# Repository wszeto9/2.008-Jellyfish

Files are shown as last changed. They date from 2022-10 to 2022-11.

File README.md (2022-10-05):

# 2.008 Jellyfish
 PCA for Jellyfish themed yo-yos for my 2.008 project

# Ordering Instructions
- [Download the manufacturing data](https://github.com/wszeto9/2.008-Jellyfish/raw/main/jellyfish_lights/production.zip)
- Head to https://cart.jlcpcb.com/quote
- Click "Add Gerber File", upload the "Gerber.zip" file from the downloaded files
- Change PCB quantity to 25
- Change PCB Color to White
- Scroll down, select PCB Assembly
- By default they should be selected: Assemble top side, Economic, tooling holes added by JLCPCB, No confirm on parts placement
- Calculated price should show $30.10. Stop if this is different.
- Choose Confirm
- May ask to create an account, please do so.
- Upload BOM, CPL file. BOM file is named bom.csv, CPL file is named positions.csv
- Product description: Research\Education\DIY\Entertainment : Toy 950300
- Click next
- On top: 153 Parts detected, 153 parts confirmed. Confirm this. If numbers are off, stop and ask.
- Press next. Confirm: Price: $103.93. If this is correct, add to cart.
- Enter shipping info
- Choose DHL Express Worldwide for shipping
- Total should be $144.02 including shipping.
- For payment, you might get a $9 coupon. Feel free to use it.
- Please forward any emails within the next 24 hours if errors pop up. The parts go through human checks, and they will email you if there's issues.

# Version info:
A01: Initial design, has incorrect values for LEDs, R4, C3
A02: Updated values for LEDs, R4,C3. PCB is the same as A01, and only BOM components changed
B01: Final PCA shape (unreleased)

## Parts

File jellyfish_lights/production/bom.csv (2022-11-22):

Designator | Footprint | Quantity | Value | LCSC Part #
BT1_9 | BatteryHolder_Keystone_3002_1x2032 | 1 | Battery_Cell
SW2_9 | tilt_switch | 1 | tilt switch
D1_9 | LED_D5.0mm_FlatTop | 1 | 3mm THT LED | C84265
SW2_8 | tilt_switch | 1 | tilt switch
SW1_9 | C_Radial_D6.3mm_H5.0mm_P2.50mm | 1 | tilt switch
D1_8 | LED_D5.0mm_FlatTop | 1 | 3mm THT LED | C84265
BT1_8 | BatteryHolder_Keystone_3002_1x2032 | 1 | Battery_Cell
D1_7 | LED_D5.0mm_FlatTop | 1 | 3mm THT LED | C84265
BT1_7 | BatteryHolder_Keystone_3002_1x2032 | 1 | Battery_Cell
SW2_7 | tilt_switch | 1 | tilt switch
SW1_8 | C_Radial_D6.3mm_H5.0mm_P2.50mm | 1 | tilt switch
SW2_6 | tilt_switch | 1 | tilt switch
SW1_7 | C_Radial_D6.3mm_H5.0mm_P2.50mm | 1 | tilt switch
BT1_6 | BatteryHolder_Keystone_3002_1x2032 | 1 | Battery_Cell
D1_6 | LED_D5.0mm_FlatTop | 1 | 3mm THT LED | C84265
SW2_5 | tilt_switch | 1 | tilt switch
BT1_5 | BatteryHolder_Keystone_3002_1x2032 | 1 | Battery_Cell
SW2_4 | tilt_switch | 1 | tilt switch
BT1_4 | BatteryHolder_Keystone_3002_1x2032 | 1 | Battery_Cell
D1_5 | LED_D5.0mm_FlatTop | 1 | 3mm THT LED | C84265
BT1_3 | BatteryHolder_Keystone_3002_1x2032 | 1 | Battery_Cell
SW2_3 | tilt_switch | 1 | tilt switch
D1_4 | LED_D5.0mm_FlatTop | 1 | 3mm THT LED | C84265
SW1_6 | C_Radial_D6.3mm_H5.0mm_P2.50mm | 1 | tilt switch
SW1_5 | C_Radial_D6.3mm_H5.0mm_P2.50mm | 1 | tilt switch
D1_3 | LED_D5.0mm_FlatTop | 1 | 3mm THT LED | C84265
BT1_2 | BatteryHolder_Keystone_3002_1x2032 | 1 | Battery_Cell
D1_2 | LED_D5.0mm_FlatTop | 1 | 3mm THT LED | C84265
SW1_4 | C_Radial_D6.3mm_H5.0mm_P2.50mm | 1 | tilt switch
SW2_2 | tilt_switch | 1 | tilt switch
BT1 | BatteryHolder_Keystone_3002_1x2032 | 1 | Battery_Cell
SW2 | tilt_switch | 1 | tilt switch
SW1_3 | C_Radial_D6.3mm_H5.0mm_P2.50mm | 1 | tilt switch
D1 | LED_D5.0mm_FlatTop | 1 | 3mm THT LED | C84265
SW1_2 | C_Radial_D6.3mm_H5.0mm_P2.50mm | 1 | tilt switch
SW1 | C_Radial_D6.3mm_H5.0mm_P2.50mm | 1 | tilt switch
D6_9 | LED_0603_1608Metric | 1 | NCD0603W1 | C84265
R2_9 | R_0603_1608Metric | 1 | 0R | C21189
JP3_9 | SolderJumper-2_P1.3mm_Open_TrianglePad1.0x1.5mm | 1 | alwaysOn
C4_9 | C_1206_3216Metric | 1 | DNP
R3_9 | R_0603_1608Metric | 1 | 10R | C22859
D2_9 | LED_0603_1608Metric | 1 | NCD0603W1 | C84265
D3_9 | LED_0603_1608Metric | 1 | NCD0603W1 | C84265
R6_9 | R_0603_1608Metric | 1 | 0R | C21189
D6_8 | LED_0603_1608Metric | 1 | NCD0603W1 | C84265
C2_9 | C_0402_1005Metric | 1 | 100nF | C1525
D3_8 | LED_0603_1608Metric | 1 | NCD0603W1 | C84265
JP3_8 | SolderJumper-2_P1.3mm_Open_TrianglePad1.0x1.5mm | 1 | alwaysOn
R1_9 | R_0402_1005Metric | 1 | 1M | C26083
C1_9 | C_0402_1005Metric | 1 | 1uF | C52923
D2_8 | LED_0603_1608Metric | 1 | NCD0603W1 | C84265
JP3_7 | SolderJumper-2_P1.3mm_Open_TrianglePad1.0x1.5mm | 1 | alwaysOn
C2_8 | C_0402_1005Metric | 1 | 100nF | C1525
JP2_9 | SolderJumper-2_P1.3mm_Open_TrianglePad1.0x1.5mm | 1 | nFade
C5_9 | C_1206_3216Metric | 1 | DNP
R2_8 | R_0603_1608Metric | 1 | 0R | C21189
C6_9 | C_1206_3216Metric | 1 | DNP
C5_8 | C_1206_3216Metric | 1 | DNP
D3_7 | LED_0603_1608Metric | 1 | NCD0603W1 | C84265
JP2_8 | SolderJumper-2_P1.3mm_Open_TrianglePad1.0x1.5mm | 1 | nFade
JP2_7 | SolderJumper-2_P1.3mm_Open_TrianglePad1.0x1.5mm | 1 | nFade
C4_8 | C_1206_3216Metric | 1 | DNP
C3_9 | C_0402_1005Metric | 1 | 4.7uF | C23733
R1_8 | R_0402_1005Metric | 1 | 1M | C26083
R5_9 | R_0603_1608Metric | 1 | 10R | C22859
C1_8 | C_0402_1005Metric | 1 | 1uF | C52923
C2_7 | C_0402_1005Metric | 1 | 100nF | C1525
D2_7 | LED_0603_1608Metric | 1 | NCD0603W1 | C84265
R3_8 | R_0603_1608Metric | 1 | 10R | C22859
D6_7 | LED_0603_1608Metric | 1 | NCD0603W1 | C84265
C3_8 | C_0402_1005Metric | 1 | 4.7uF | C23733
D2_6 | LED_0603_1608Metric | 1 | NCD0603W1 | C84265
C2_6 | C_0402_1005Metric | 1 | 100nF | C1525
C3_7 | C_0402_1005Metric | 1 | 4.7uF | C23733
U1_9 | SOT-23-5 | 1 | SN74LVC1G14DBVR | C434069
C1_7 | C_0402_1005Metric | 1 | 1uF | C52923
C4_7 | C_1206_3216Metric | 1 | DNP
Q1_9 | SOT-23 | 1 | AO3400A | C347475
R2_7 | R_0603_1608Metric | 1 | 0R | C21189
R2_6 | R_0603_1608Metric | 1 | 0R | C21189
JP3_6 | SolderJumper-2_P1.3mm_Open_TrianglePad1.0x1.5mm | 1 | alwaysOn
R6_8 | R_0603_1608Metric | 1 | 0R | C21189
Q1_8 | SOT-23 | 1 | AO3400A | C347475
C3_6 | C_0402_1005Metric | 1 | 4.7uF | C23733
U1_8 | SOT-23-5 | 1 | SN74LVC1G14DBVR | C434069
Q1_7 | SOT-23 | 1 | AO3400A | C347475
JP2_6 | SolderJumper-2_P1.3mm_Open_TrianglePad1.0x1.5mm | 1 | nFade
C4_6 | C_1206_3216Metric | 1 | DNP
R3_7 | R_0603_1608Metric | 1 | 10R | C22859
D2_5 | LED_0603_1608Metric | 1 | NCD0603W1 | C84265
D7_9 | LED_0603_1608Metric | 1 | NCD0603W1 | C84265
C5_7 | C_1206_3216Metric | 1 | DNP
R4_9 | R_0402_1005Metric | 1 | 330k | C25778
U1_7 | SOT-23-5 | 1 | SN74LVC1G14DBVR | C434069
C6_8 | C_1206_3216Metric | 1 | DNP
U1_6 | SOT-23-5 | 1 | SN74LVC1G14DBVR | C434069
C2_5 | C_0402_1005Metric | 1 | 100nF | C1525
R4_8 | R_0402_1005Metric | 1 | 330k | C25778
Q1_6 | SOT-23 | 1 | AO3400A | C347475
D6_6 | LED_0603_1608Metric | 1 | NCD0603W1 | C84265
D3_6 | LED_0603_1608Metric | 1 | NCD0603W1 | C84265
C1_6 | C_0402_1005Metric | 1 | 1uF | C52923
R5_8 | R_0603_1608Metric | 1 | 10R | C22859
D7_8 | LED_0603_1608Metric | 1 | NCD0603W1 | C84265
C1_5 | C_0402_1005Metric | 1 | 1uF | C52923
D6_5 | LED_0603_1608Metric | 1 | NCD0603W1 | C84265
JP3_5 | SolderJumper-2_P1.3mm_Open_TrianglePad1.0x1.5mm | 1 | alwaysOn
R5_7 | R_0603_1608Metric | 1 | 10R | C22859
D7_7 | LED_0603_1608Metric | 1 | NCD0603W1 | C84265
R2_5 | R_0603_1608Metric | 1 | 0R | C21189
C6_7 | C_1206_3216Metric | 1 | DNP
R6_7 | R_0603_1608Metric | 1 | 0R | C21189
R4_7 | R_0402_1005Metric | 1 | 330k | C25778
C4_5 | C_1206_3216Metric | 1 | DNP
JP2_5 | SolderJumper-2_P1.3mm_Open_TrianglePad1.0x1.5mm | 1 | nFade
JP3_4 | SolderJumper-2_P1.3mm_Open_TrianglePad1.0x1.5mm | 1 | alwaysOn
D2_4 | LED_0603_1608Metric | 1 | NCD0603W1 | C84265
C6_6 | C_1206_3216Metric | 1 | DNP
C1_4 | C_0402_1005Metric | 1 | 1uF | C52923
Q1_5 | SOT-23 | 1 | AO3400A | C347475
D3_5 | LED_0603_1608Metric | 1 | NCD0603W1 | C84265
U1_5 | SOT-23-5 | 1 | SN74LVC1G14DBVR | C434069
C1_3 | C_0402_1005Metric | 1 | 1uF | C52923
Q1_4 | SOT-23 | 1 | AO3400A | C347475
D7_6 | LED_0603_1608Metric | 1 | NCD0603W1 | C84265
R5_6 | R_0603_1608Metric | 1 | 10R | C22859
D6_4 | LED_0603_1608Metric | 1 | NCD0603W1 | C84265
Q1_3 | SOT-23 | 1 | AO3400A | C347475
R6_6 | R_0603_1608Metric | 1 | 0R | C21189
C4_4 | C_1206_3216Metric | 1 | DNP
R3_6 | R_0603_1608Metric | 1 | 10R | C22859
D3_4 | LED_0603_1608Metric | 1 | NCD0603W1 | C84265
R4_6 | R_0402_1005Metric | 1 | 330k | C25778
C6_5 | C_1206_3216Metric | 1 | DNP
C3_5 | C_0402_1005Metric | 1 | 4.7uF | C23733
R3_5 | R_0603_1608Metric | 1 | 10R | C22859
JP3_3 | SolderJumper-2_P1.3mm_Open_TrianglePad1.0x1.5mm | 1 | alwaysOn
C6_4 | C_1206_3216Metric | 1 | DNP
R4_5 | R_0402_1005Metric | 1 | 330k | C25778
R4_4 | R_0402_1005Metric | 1 | 330k | C25778
D6_3 | LED_0603_1608Metric | 1 | NCD0603W1 | C84265
D7_5 | LED_0603_1608Metric | 1 | NCD0603W1 | C84265
R6_5 | R_0603_1608Metric | 1 | 0R | C21189
U1_4 | SOT-23-5 | 1 | SN74LVC1G14DBVR | C434069
R3_4 | R_0603_1608Metric | 1 | 10R | C22859
C5_6 | C_1206_3216Metric | 1 | DNP
C5_5 | C_1206_3216Metric | 1 | DNP
R4_3 | R_0402_1005Metric | 1 | 330k | C25778
R6_4 | R_0603_1608Metric | 1 | 0R | C21189
Q1_2 | SOT-23 | 1 | AO3400A | C347475
C4_3 | C_1206_3216Metric | 1 | DNP
C5_4 | C_1206_3216Metric | 1 | DNP
R5_5 | R_0603_1608Metric | 1 | 10R | C22859
D3_3 | LED_0603_1608Metric | 1 | NCD0603W1 | C84265
R1_7 | R_0402_1005Metric | 1 | 1M | C26083
D6_2 | LED_0603_1608Metric | 1 | NCD0603W1 | C84265
R3_3 | R_0603_1608Metric | 1 | 10R | C22859
R1_6 | R_0402_1005Metric | 1 | 1M | C26083
C4_2 | C_1206_3216Metric | 1 | DNP
R4_2 | R_0402_1005Metric | 1 | 330k | C25778
C6_3 | C_1206_3216Metric | 1 | DNP
JP3_2 | SolderJumper-2_P1.3mm_Open_TrianglePad1.0x1.5mm | 1 | alwaysOn
R6_3 | R_0603_1608Metric | 1 | 0R | C21189
C1_2 | C_0402_1005Metric | 1 | 1uF | C52923
R3_2 | R_0603_1608Metric | 1 | 10R | C22859
JP3 | SolderJumper-2_P1.3mm_Open_TrianglePad1.0x1.5mm | 1 | alwaysOn
D7_4 | LED_0603_1608Metric | 1 | NCD0603W1 | C84265
R4 | R_0402_1005Metric | 1 | 330k | C25778
C5_3 | C_1206_3216Metric | 1 | DNP
C4 | C_1206_3216Metric | 1 | DNP
C3_4 | C_0402_1005Metric | 1 | 4.7uF | C23733
JP2_4 | SolderJumper-2_P1.3mm_Open_TrianglePad1.0x1.5mm | 1 | nFade
R2_4 | R_0603_1608Metric | 1 | 0R | C21189
C5_2 | C_1206_3216Metric | 1 | DNP
U1_3 | SOT-23-5 | 1 | SN74LVC1G14DBVR | C434069
C3_3 | C_0402_1005Metric | 1 | 4.7uF | C23733
R5_4 | R_0603_1608Metric | 1 | 10R | C22859
C3_2 | C_0402_1005Metric | 1 | 4.7uF | C23733
JP2_3 | SolderJumper-2_P1.3mm_Open_TrianglePad1.0x1.5mm | 1 | nFade
Q1 | SOT-23 | 1 | AO3400A | C347475
R5_3 | R_0603_1608Metric | 1 | 10R | C22859
R5_2 | R_0603_1608Metric | 1 | 10R | C22859
JP2_2 | SolderJumper-2_P1.3mm_Open_TrianglePad1.0x1.5mm | 1 | nFade
R2_3 | R_0603_1608Metric | 1 | 0R | C21189
C1 | C_0402_1005Metric | 1 | 1uF | C52923
C2_4 | C_0402_1005Metric | 1 | 100nF | C1525
R1_5 | R_0402_1005Metric | 1 | 1M | C26083
R2_2 | R_0603_1608Metric | 1 | 0R | C21189
R1_4 | R_0402_1005Metric | 1 | 1M | C26083
D6 | LED_0603_1608Metric | 1 | NCD0603W1 | C84265
R3 | R_0603_1608Metric | 1 | 10R | C22859
U1_2 | SOT-23-5 | 1 | SN74LVC1G14DBVR | C434069
D2_3 | LED_0603_1608Metric | 1 | NCD0603W1 | C84265
D2_2 | LED_0603_1608Metric | 1 | NCD0603W1 | C84265
D7_3 | LED_0603_1608Metric | 1 | NCD0603W1 | C84265
D2 | LED_0603_1608Metric | 1 | NCD0603W1 | C84265
D3_2 | LED_0603_1608Metric | 1 | NCD0603W1 | C84265
D7_2 | LED_0603_1608Metric | 1 | NCD0603W1 | C84265
D7 | LED_0603_1608Metric | 1 | NCD0603W1 | C84265
C6_2 | C_1206_3216Metric | 1 | DNP
JP2 | SolderJumper-2_P1.3mm_Open_TrianglePad1.0x1.5mm | 1 | nFade
U1 | SOT-23-5 | 1 | SN74LVC1G14DBVR | C434069
R1_3 | R_0402_1005Metric | 1 | 1M | C26083
R1_2 | R_0402_1005Metric | 1 | 1M | C26083
D3 | LED_0603_1608Metric | 1 | NCD0603W1 | C84265
C2_3 | C_0402_1005Metric | 1 | 100nF | C1525
C3 | C_0402_1005Metric | 1 | 4.7uF | C23733
C2_2 | C_0402_1005Metric | 1 | 100nF | C1525
R1 | R_0402_1005Metric | 1 | 1M | C26083
R5 | R_0603_1608Metric | 1 | 10R | C22859
R6_2 | R_0603_1608Metric | 1 | 0R | C21189
C5 | C_1206_3216Metric | 1 | DNP
C6 | C_1206_3216Metric | 1 | DNP
R6 | R_0603_1608Metric | 1 | 0R | C21189
C2 | C_0402_1005Metric | 1 | 100nF | C1525
R2 | R_0603_1608Metric | 1 | 0R | C21189

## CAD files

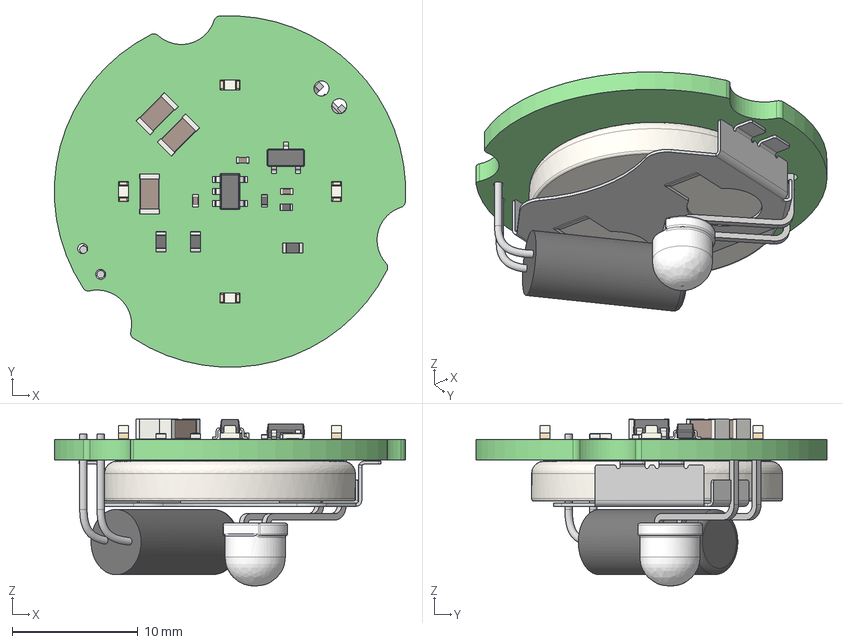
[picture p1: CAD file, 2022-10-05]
jellyfish_lights/jellyfish_lights.step
28.0 x 28.0 x 13.3 mm
jellyfish_lights PCB

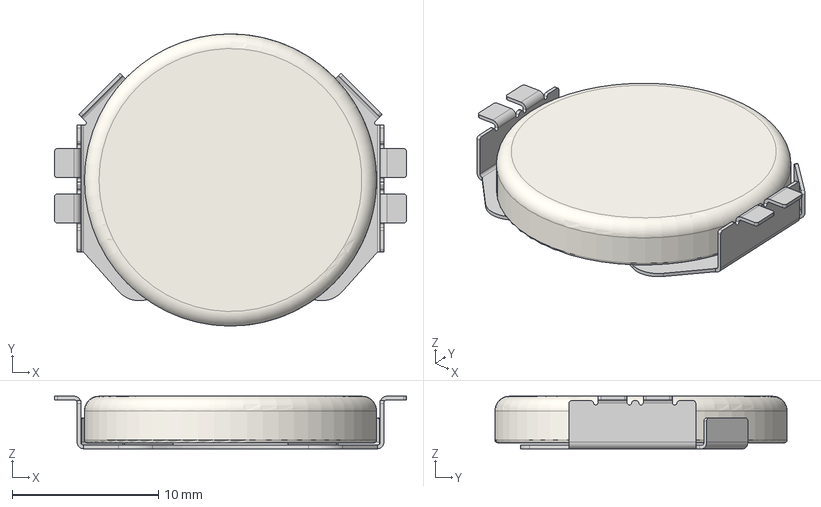
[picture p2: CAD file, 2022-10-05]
jellyfish_lights/Parts/CR2032.step
24.1 x 20.0 x 3.60 mm

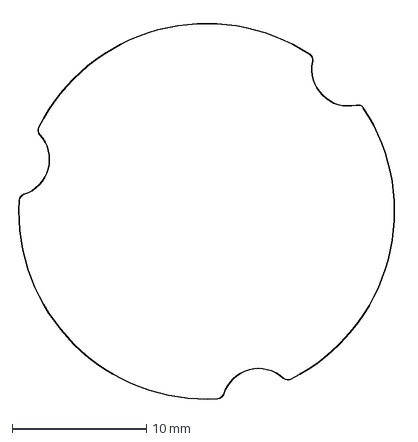
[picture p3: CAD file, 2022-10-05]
jellyfish_lights/outline.dxf
28.8 x 28.8 mm

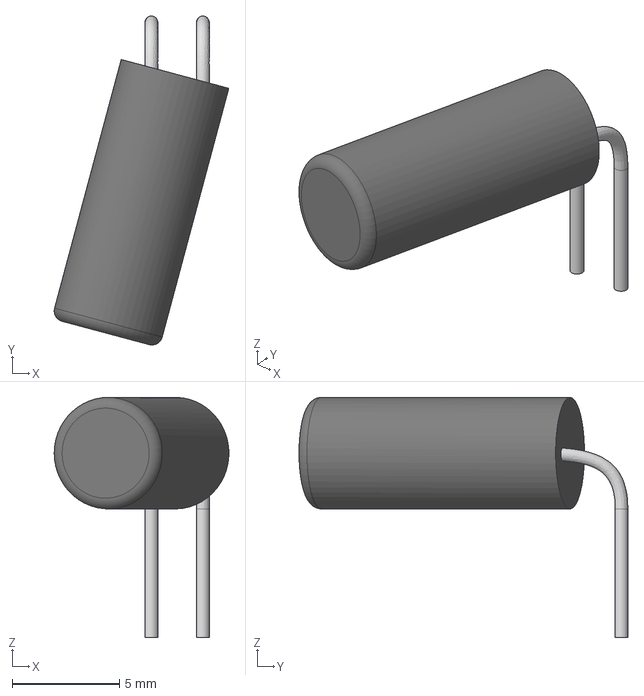
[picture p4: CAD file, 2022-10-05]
jellyfish_lights/Parts/tilt switch.step
8.14 x 15.3 x 11.2 mm

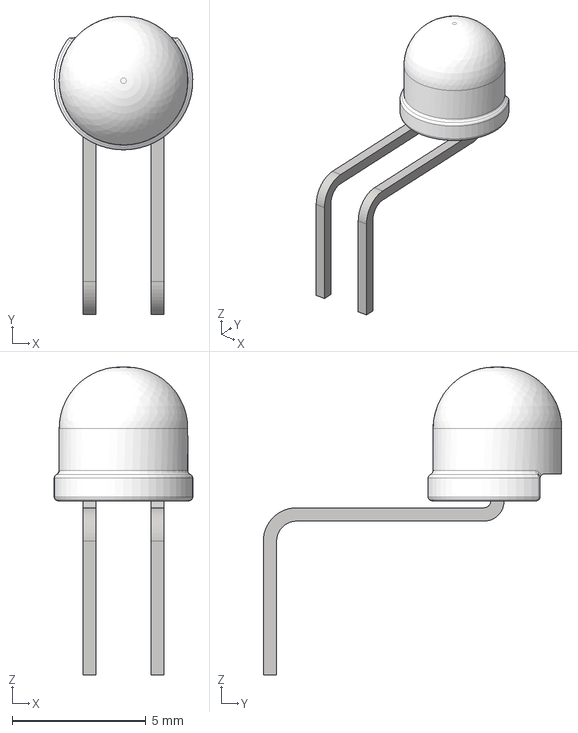
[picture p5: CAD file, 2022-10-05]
jellyfish_lights/Parts/led 3mm.step
5.18 x 11.2 x 11.5 mm

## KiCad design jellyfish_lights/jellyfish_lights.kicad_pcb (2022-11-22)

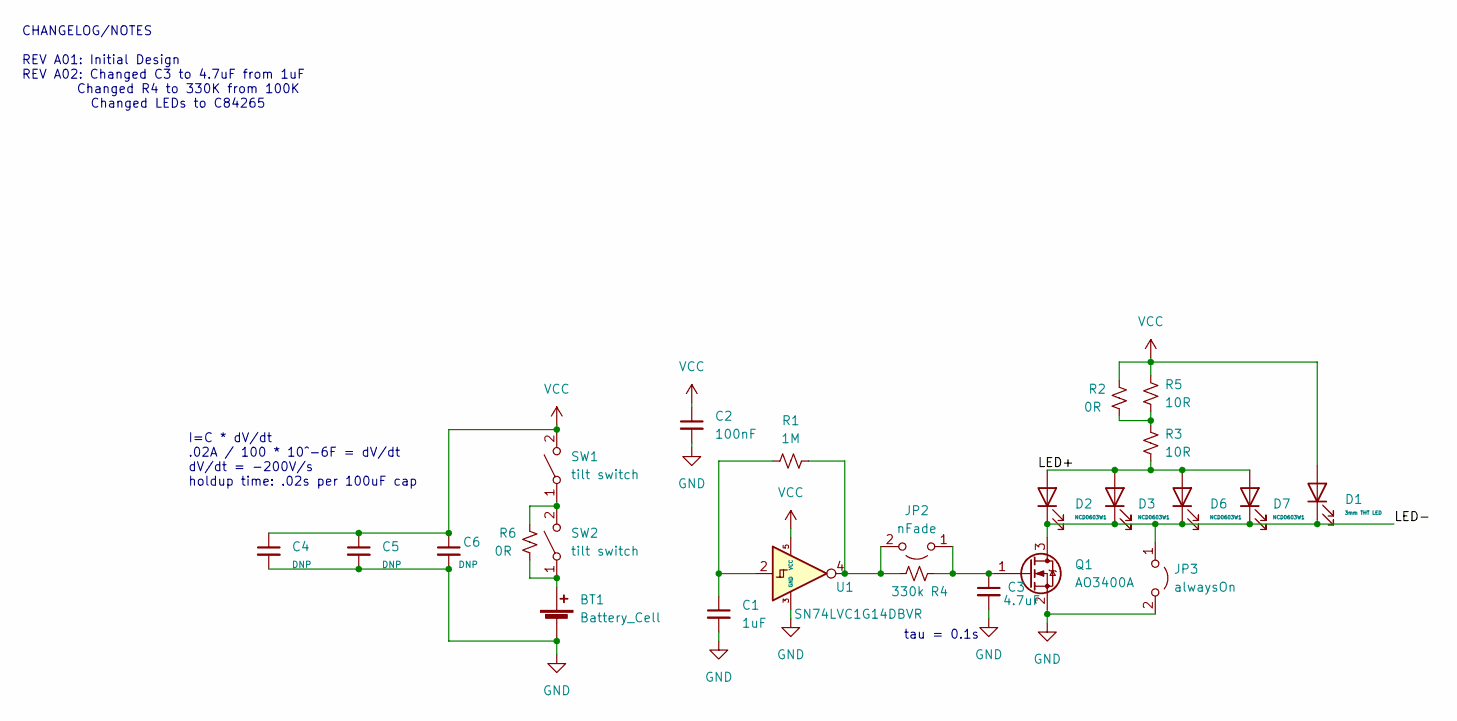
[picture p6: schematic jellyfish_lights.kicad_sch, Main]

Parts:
BT1: Battery_Cell; BatteryHolder_Keystone_3002_1x2032
C1: 1uF; C_0402_1005Metric; LCSC C52923
C2: 100nF; C_0402_1005Metric; LCSC C1525
C3: 4.7uF; C_0402_1005Metric; LCSC C23733
C4, C5, C6: DNP; C_1206_3216Metric
D1: 3mm THT LED; LED_D5.0mm_FlatTop; LCSC C84265
D2, D3, D6, D7: NCD0603W1; LED_0603_1608Metric; LCSC C84265
JP2: nFade; SolderJumper-2_P1.3mm_Open_TrianglePad1.0x1.5mm
JP3: alwaysOn; SolderJumper-2_P1.3mm_Open_TrianglePad1.0x1.5mm
Q1: AO3400A; SOT-23; LCSC C347475
R1: 1M; R_0402_1005Metric; LCSC C26083
R2, R6: 0R; R_0603_1608Metric; LCSC C21189
R3, R5: 10R; R_0603_1608Metric; LCSC C22859
R4: 330k; R_0402_1005Metric; LCSC C25778
SW1, SW2: tilt switch; tilt_switch
U1: SN74LVC1G14DBVR; SOT-23-5; LCSC C434069

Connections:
/LED+: D2.2 (A), D3.2 (A), D6.2 (A), D7.2 (A), R3.2
/LED-: D1.1 (K), D2.1 (K), D3.1 (K), D6.1 (K), D7.1 (K), JP3.1 (A), Q1.3 (D)
GND: BT1.2 (-), C1.2, C2.2, C3.2, C4.2, C5.2, C6.2, JP3.2 (B), Q1.2 (S), U1.3 (GND)
unnamed: BT1.1 (+), R6.1, SW2.1 (A)
unnamed: C1.1, R1.1, U1.2
unnamed: C3.1, JP2.1 (A), Q1.1 (G), R4.2
unnamed: JP2.2 (B), R1.2, R4.1, U1.4
unnamed: R2.1, R3.1, R5.2
unnamed: R6.2, SW1.1 (A), SW2.2 (B)
VCC: C2.1, C4.1, C5.1, C6.1, D1.2 (A), R2.2, R5.1, SW1.2 (B), U1.5 (VCC)

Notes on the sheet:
tau = 0.1s
I=C * dV/dt .02A / 100 * 10^-6F = dV/dt dV/dt = -200V/s holdup time: .02s per 100uF cap
CHANGELOG/NOTES REV A01: Initial Design REV A02: Changed C3 to 4.7uF from 1uF Changed R4 to 330K from 100K Changed LEDs to C84265

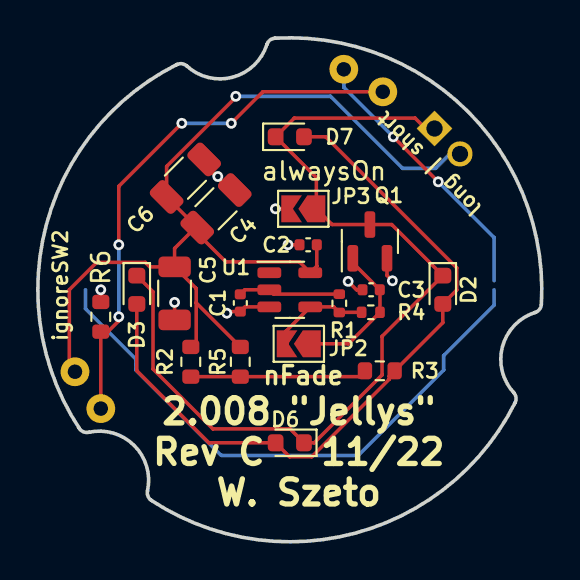
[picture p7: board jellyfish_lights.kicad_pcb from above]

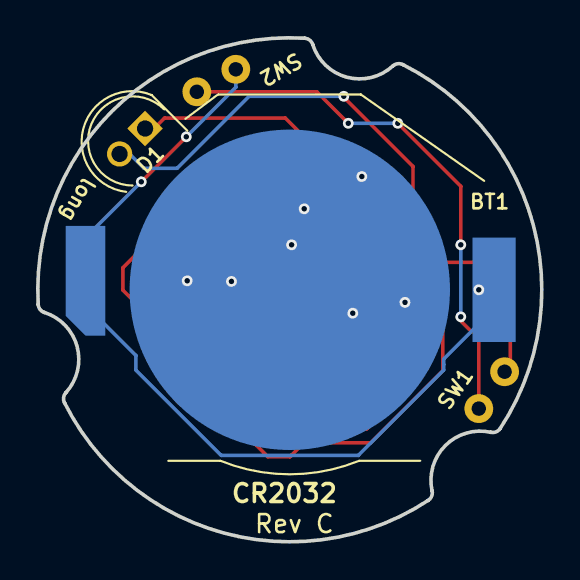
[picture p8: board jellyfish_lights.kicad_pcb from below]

Board: 2 copper layers, 28.0 x 28.0 mm, 24 parts (4 on the bottom side), 10 nets.

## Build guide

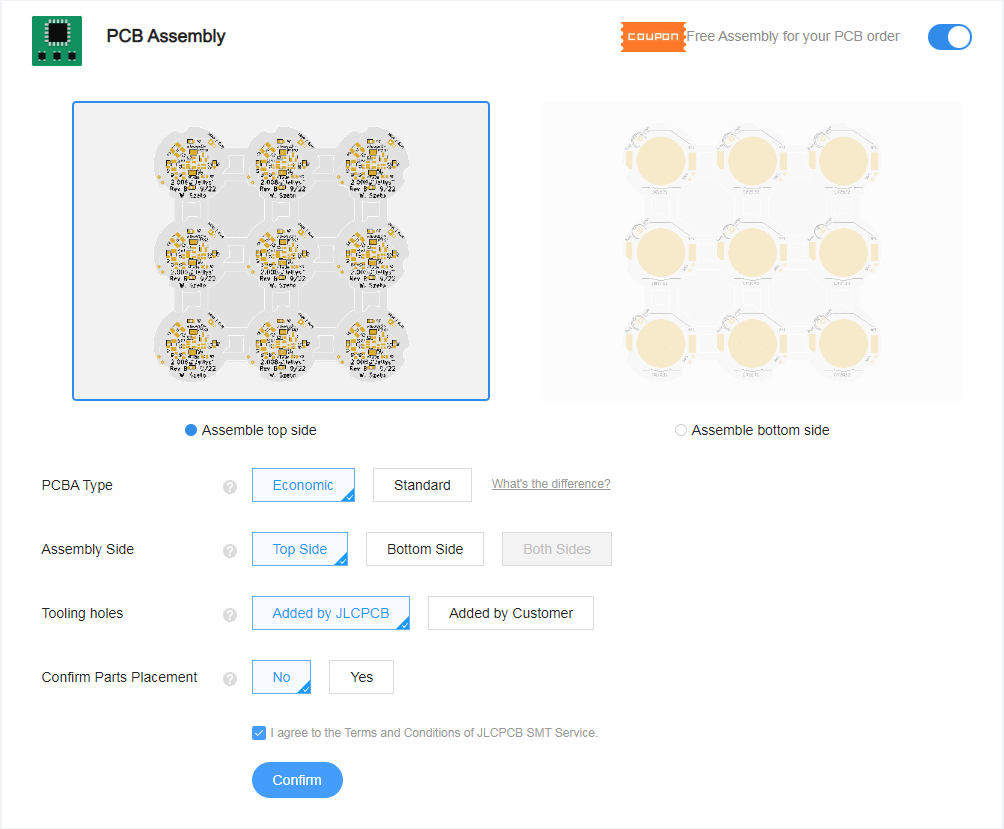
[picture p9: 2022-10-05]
documentation/pcb_assembly_select.png

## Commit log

2022-09-17 designed circuit
    [CR2032.step, jellyfish_lights.kicad_pcb, jellyfish_lights.kicad_sch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]
2022-09-22 edited BOM
    Changed C3 to 4.7uF from 1uF
    Changed R4 to 330K from 100K
    Changed LEDs to C84265
    [jellyfish_lights.kicad_sch]
2022-10-05 Rev B01
    Changed board shape
    [CR2032.step, jellyfish_lights.kicad_pcb, jellyfish_lights.kicad_sch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]
2022-11-21 Rev C01
    -Edited THT footprints to accommodate easier soldering (moved away from BT1)
    -Added SW2 to prevent turn-on events while not spinning
    [jellyfish_lights.kicad_pcb, jellyfish_lights.kicad_sch, jellyfish_lights_panelized.kicad_pcb]
2022-11-22 changed jumper to 0R resistor for ignoreSW2
    [jellyfish_lights.kicad_pcb, jellyfish_lights.kicad_sch, jellyfish_lights_panelized.kicad_pcb]
2022-11-22 Updated BOM/POS file
    [bom.csv, jellyfish_lights.kicad_pcb, jellyfish_lights.kicad_sch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]
2022-11-22 fixing LCSC numbers
    [bom.csv, jellyfish_lights.kicad_pcb, jellyfish_lights.kicad_sch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]
